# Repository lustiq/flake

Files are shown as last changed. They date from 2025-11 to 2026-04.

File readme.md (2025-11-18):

**English** | [简体中文](./docs/internationalization/Chinese/readme.md) | [Русский](./docs/internationalization/Russian/readme.md) | *`More languages are in progress!`*

***

<div align="center">
    Flake Keyboard Poster
    <h3>Anywhy Flake</h3>
    <p><i>An open-source, wireless, split ergonomic keyboard designed to be productive, healthy, and enjoyable.</i></p>
    <p>
        
        
        
    </p>
</div>

## Why Flake?

By the 19th century, a need for a faster way of writing had emerged, leading to the invention of typewriters. Two centuries later, modern keyboards don't look much different, even though their monolithic, row-staggered design has been proven to be inefficient and often harmful.

The Flake keyboard addresses these problems from the ground up, providing huge benefits in comfort and efficiency for anyone who spends their day typing.

## Core Features

*   **Split Ergonomic Design:** Place each half where it feels best, eliminating wrist strain.
*   **Columnar Stagger:** Keys are arranged to follow the natural movement of your fingers.
*   **Wireless First:** True wireless freedom with Bluetooth LE powered by ZMK Firmware.
*   **Hybrid Hot-Swap:** Supports **MX**, **Kailh Choc v1** and **Kailh Choc v2** switches.
*   **Three Sizes:** Choose the layout that fits you perfectly: **Small (40)**, **Medium (46)**, or **Large (58)** keys.
*   **Ultra-Thin Profile:** An incredibly sleek and low-profile body for maximum comfort.
*   **Fully Open Source:** All hardware and software files are available for you to build, modify, and share.

## The Philosophy Behind the Design

### Split Layout
Regular keyboards force your forearms to converge, bending your wrists at an unnatural angle that can lead to long-term pain. A split keyboard allows you to position each half independently, aligning your hands, wrists, and forearms in a straight, comfortable line. As a bonus, you get free space between the halves for a trackpad, notebook, or even a cat =^..^=

Ergonomic positioning of a split keyboard

### Columnar Stagger
Look at your hand - your fingers have different lengths and prefer to move up and down. Now look at a traditional keyboard - the keys are shifted horizontally. This "row stagger" forces your fingers to make awkward, unnatural movements. Flake uses a "columnar stagger", where each column is shifted vertically to match the natural reach of your fingers, resulting in a much more pleasant and efficient typing experience.

row-based stagger keyboard image

Comparison of row stagger and column stagger

### Hybrid Switch Support
The world of mechanical switches is vast and exciting, but choosing just one type can be limiting. Flake solves this with hybrid hot-swap sockets. Each key position has sockets for both **Cherry MX-style** and **low-profile Kailh Choc** switches. This gives you the freedom to experiment with different switch types at any time.

To provide the best typing feel and stability for the taller MX switches, a dedicated switch plate is included with the case files. This plate is placed over the PCB before inserting the switches, ensuring they are held securely. Low-profile Choc switches mount directly and do not require the plate.

Flake keyboard showing both MX and Choc switches

### Fewer Keys, More Power
A small key count might seem counterintuitive for productivity, but it's a core feature, not a compromise. Fewer keys mean your hands stay in one place, eliminating the need to stretch for distant keys.

This doesn't mean less functionality. Powered by the incredible [ZMK Firmware](https://zmk.dev), Flake uses [layers](https://zmk.dev/docs/keymaps#layers) to access every key a traditional keyboard has and more. You can have dedicated layers for numbers, symbols, navigation, macros, and anything else you can imagine, all just a thumb press away.

Visual representation of keyboard layers in ZMK

To accommodate different preferences, Flake comes in three sizes:
*   **Flake L (58 keys):** For those who prefer more dedicated keys.
*   **Flake M (46 keys):** A perfect balance of function and form.
*   **Flake S (40 keys):** For the ultimate in minimalism and ergonomics.

Flake L keyboard

### Ultra-Thin Profile
The keyboard body is only **~9mm** thick (without feet). Combined with low-profile Choc switches and keycaps, this creates an extremely low-to-the-desk typing experience, further reducing wrist strain.

Side profile showing the thinness of the Flake keyboard

## Build Your Own Flake

Ready to build one? The comprehensive build guide has everything you need to get started.
➡️ **[Read the Official Build Guide](./docs/build_guide.md)**

Also, be sure to check out the gallery to see amazing builds from the community!
➡️ **[Explore the Gallery ✨](./docs/gallery.md)**

## Credits

Huge thanks to:
-   [@foostan](https://github.com/foostan) for the [Corne Keyboard](https://github.com/foostan/crkbd), my introduction to the world of ergonomic keyboards.
-   [@pashutk](https://github.com/pashutk) for the [Chocofi](https://github.com/pashutk/chocofi), an amazing tiny keyboard I've been using for a while.
-   [@josefadamcik](https://github.com/josefadamcik) for the [Sofle](https://github.com/josefadamcik/SofleKeyboard), which heavily inspired the Flake's key layout.
-   [@carrefinho](https://github.com/carrefinho) for the [Forager](https://github.com/carrefinho/forager). Its clever controller mount allowed v2 to use the Seeed Xiao controller while keeping the keyboard thin.
-   [@ebastler](https://github.com/ebastler/) for his amazing [marbastlib](https://github.com/ebastler/marbastlib), which is used as the basis for the switch footprints.
-   [@petejohanson](https://github.com/petejohanson) and all the [contributors](https://github.com/zmkfirmware/zmk/graphs/contributors) for creating and maintaining the incredible [ZMK Firmware](https://github.com/zmkfirmware/zmk).
-   Everyone working on [KiCad](https://gitlab.com/kicad/code/kicad) and [FreeCAD](https://github.com/FreeCAD/FreeCAD) for creating such powerful open source tools.
-   The helpful and kind people from the [ZMK Discord server](https://zmk.dev/community/discord/invite) who helped me learn PCB design and solve countless problems.
-   Thank you to everyone who explores unpopular technologies, digs into niche topics, and makes amazing things possible.

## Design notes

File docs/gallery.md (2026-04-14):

# Anywhy Flake Gallery

Welcome to the gallery, here you will find amazing Flake builds made by people. This page will be constantly expanding, so if you have a build you want to share, feel free to contact me and I'll add it here.

## by [@Constant_Pin_7757](https://www.reddit.com/r/ErgoMechKeyboards/comments/1q6lvwh/comment/ny8om0r/)

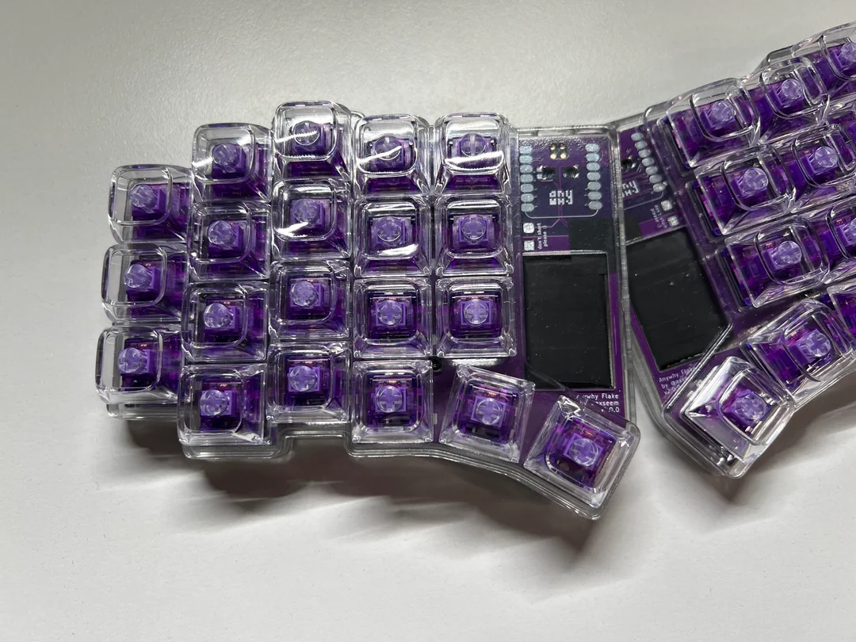
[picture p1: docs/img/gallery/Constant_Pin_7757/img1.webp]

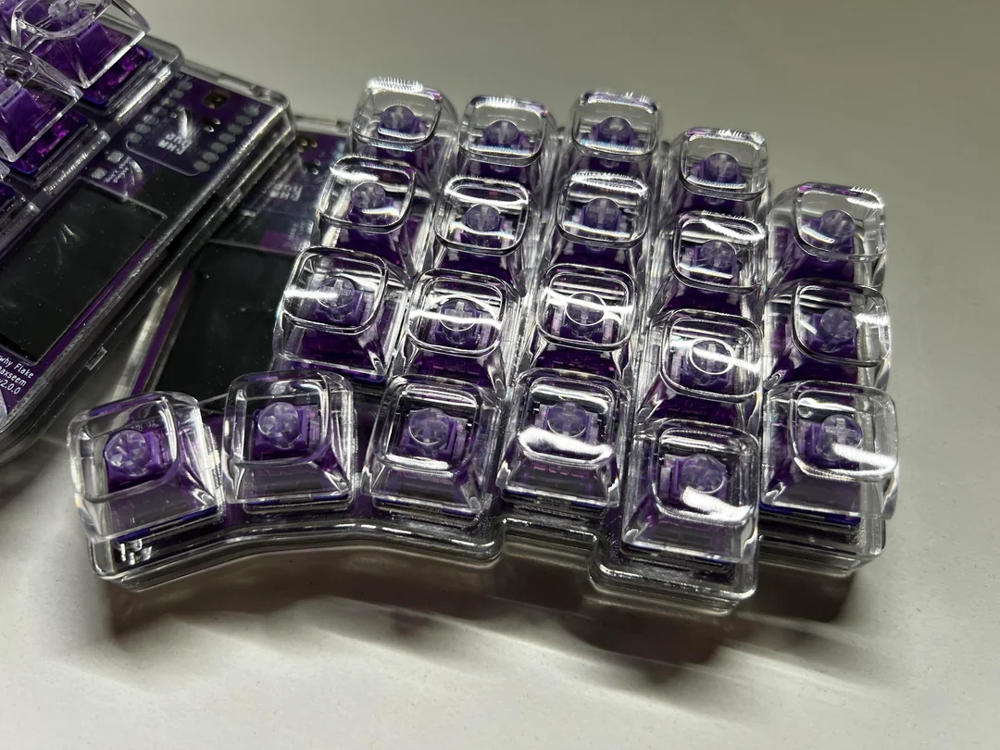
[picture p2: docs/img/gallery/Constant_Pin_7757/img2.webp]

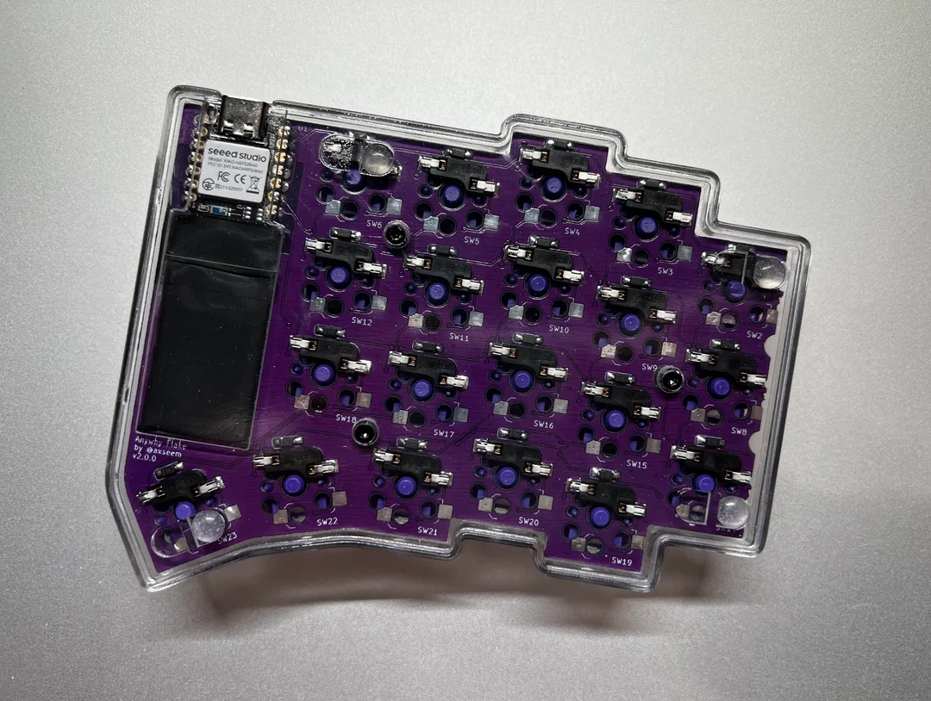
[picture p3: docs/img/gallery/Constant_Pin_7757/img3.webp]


Flake S with transparent housing, lavender PCB and MX switches

## by [@peppapighs](https://www.reddit.com/r/ErgoMechKeyboards/comments/1jbw0kt/my_custom_flake/)

flake image
flake image

Flake S with modified PCB adding through-holes for MCU mounting

## by [@caiodelgado](https://www.reddit.com/r/ErgoMechKeyboards/comments/1iz07kw/anywhy_flake_choc_v1_robinsunset_tenting/)

Flake with Choc v1 Robin switches, 3d-printed keycaps and tenting legs

flake image
flake image

## by [@kurisutofujp](https://www.reddit.com/r/ErgoMechKeyboards/comments/1iirgyt/comment/mb9034h/)

Snow-white Flake L with MX switches

flake image

## by [@devpew](https://www.reddit.com/r/ErgoMechKeyboards/comments/1ieevvh/flake/)

Clean white Flake M with black keyscaps

flake image

## by [@CaptLynx](https://www.reddit.com/r/ErgoMechKeyboards/comments/1ic3nkc/caitlynarcane_themed_anywhy_flake/)

The design is inspired by Caitlin, a character from the Arcane series.

flake image

flake image

flake image

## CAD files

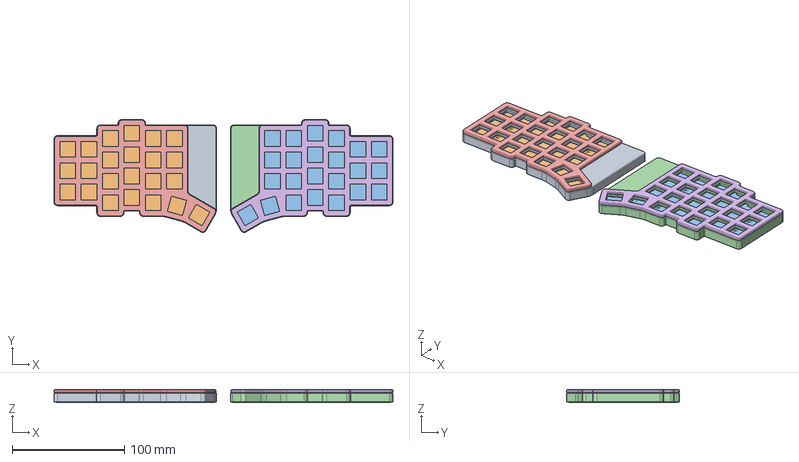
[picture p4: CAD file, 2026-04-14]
enclosure/Enclosure.FCStd
301.4 x 100.4 x 11.3 mm
Top-Left
Bottom-Left001
Bottom-Right001
Top-Right
Plate-Left
Plate-Right

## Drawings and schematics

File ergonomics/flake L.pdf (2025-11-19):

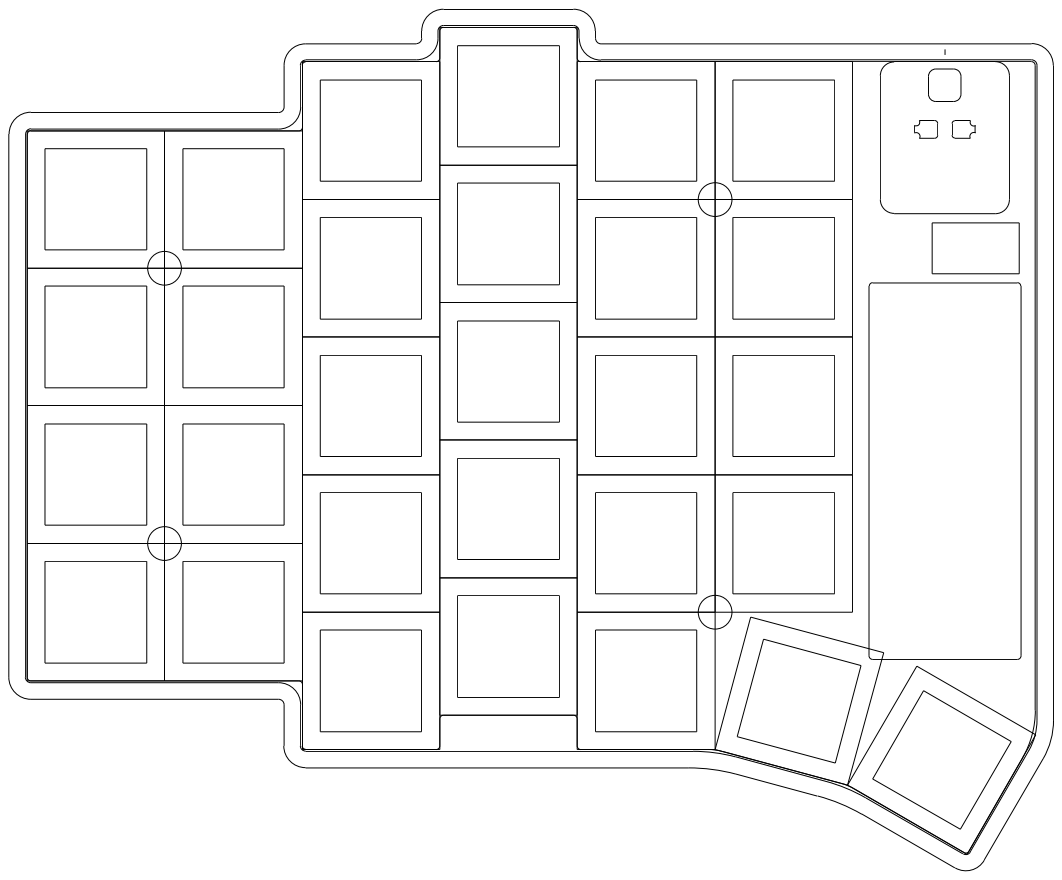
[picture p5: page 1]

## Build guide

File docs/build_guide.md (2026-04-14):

**English** | [简体中文](./internationalization/Chinese/build_guide.md) | [Русский](./internationalization/Russian/build_guide.md)

# Flake Keyboard Build Guide

Welcome to the official build guide for the Flake keyboard! This guide is designed to be comprehensive and easy to follow, even if this is your first time building a keyboard.

I recommend reading through the entire guide once before you begin to familiarize yourself with the process.

## Prerequisites

Before you start soldering or assembling, make sure you have all the necessary components and tools.

### Required Tools

- **Soldering Iron:** A quality soldering iron with adjustable temperature control is essential.
- **Solder:** Lead-free solder is strongly recommended for health and safety.
- **Flux:** A flux pen or paste will make soldering significantly easier.
- **Tweezers:** Essential for handling small components.
- **Screwdriver:** For the M2 screws used in the case.
- **(Optional) Multimeter:** Useful for troubleshooting.

### Required Files

You will need the manufacturing files for the PCB and the enclosure. You can find all the necessary files and instructions on where to order them here:
➡️ **[Essential Files and Ordering Guide](essential_files.md)**

### Bill of Materials (BOM)

The required components vary based on the size of the keyboard you are building. The number of keys for each size is:

- **Small:** 40 keys
- **Medium:** 46 keys
- **Large:** 58 keys

| Component | Small (40) | Medium (46) | Large (58) | Notes |
| :---| :---: | :---: | :---: | :--- |
| **Soldering Components** | | | | |
| Anywhy Flake v2 PCB | 2 | 2 | 2 | One for each half |
| Seeed Xiao nRF52840 | 2 | 2 | 2 | The microcontroller |
| JST 1.25 SMD 2pin Horizontal Connector | 2 | 2 | 2 | For the battery |
| MX Hot-swap Sockets | 40 | 46 | 58 | See note below |
| Choc Hot-swap Sockets | 40 | 46 | 58 | See note below |
| 1N4148 Diodes | 40 | 46 | 58 | 1 per switch (SOD-123 or SOD-323) |
| **Assembly Components** | | | | |
| Soldered PCB | 2 | 2 | 2 | From the step above |
| Switches (Choc v1/v2 or MX) | 40 | 46 | 58 | 1 per socket |
| Keycaps | 40 | 46 | 58 | Must be compatible with your switches |
| Enclosure | 1 set | 1 set | 1 set | Includes top and bottom parts for each half |
| 502030 LiPo Battery (up to 502050 for Flake L) | 2 | 2 | 2 | Or smaller, with a JST 1.25 plug |
| 6x2mm Rubber Feet | 8 | 8 | 8 | |
| M2x4mm Stand-offs | 6 | 8 | 8 | |
| M2x4mm Flat Countersunk Screws | 12 | 16 | 16 | e.g., DIN965 |

> [!NOTE]
> **Sockets:** The Flake PCB supports both MX and Choc switches simultaneously. This guide shows you how to solder both socket types for maximum flexibility. If you are certain you will only ever use one type of switch, you can choose to solder only the corresponding sockets (MX or Choc) and omit the other set.

---

## 1. Soldering the PCB

This is the most detailed part of the build. Take your time, work in a well-ventilated area, and double-check your work as you go. Always use flux, start with a small amount of solder and add more if needed.

### Preparation

#### A. Understand the Reversible PCB

The Flake uses a **reversible PCB**. This means you use the same PCB design for both the left and right halves - you just flip one over. The assembly process is identical for both halves. This guide will walk you through building one half. **Simply repeat all steps on the second PCB, ensuring it is flipped to the opposite side.**

Two reversible Flake PCBs

#### B. Clean the Holes Under the Controller

Due to the manufacturing process, the controller pin holes may be partially obstructed. Before placing the controller, you must carefully clear these obstructions using a tip of your tweezers.

Before and after cleaning the controller pin holes

#### C. Break the PCB (Small Version Only)

If you are building the 40-key **Small** version, as I do in this guide, you must snap off the outer pinky column from both PCBs. **If you are building the Medium or Large version, skip this step and leave the PCBs intact.**

Breaking off the outer column for the Small version

#### D. Prepare Your Components

Lay out the PCB and the components you will be soldering for one half.

All components for soldering one PCB half

### Step 1: Battery Connector (JST)

> [!TIP]
> If your battery doesn't have a JST plug, you can solder it directly to the `RAW` (+) and `GND` (-) pads next to the JST footprint. However, this is not recommended as it makes the battery difficult to replace later.

1. Place the JST 1.25 connector onto its footprint at position `BT1`.
2. Solder the two large mounting pads to secure connector.
3. Solder the two small pins.

Soldering the JST battery connector

### Step 2: Controller (Seeed Xiao)

> [!IMPORTANT]
> Proper alignment is critical. A misaligned controller may prevent the keyboard from fitting into the enclosure.

1. Place the Xiao controller onto its footprint inside the `U1` outline. The USB-C port should face outwards.
2. Solder **one corner pin** to tack the controller in place.
3. Check the alignment. If it's crooked, re-heat the pin and adjust.
4. Once aligned, solder the **diagonally opposite corner pin** to lock it in place.

Tacking opposite corner pins of the controller first

5. Proceed to solder all remaining pins.

All controller pins soldered

6. Flip the PCB and solder the `RAW` and `GND` pads under the controller.

Soldering the RAW and GND pads under the controller

### Step 3: Diodes

> [!WARNING]
> Diodes are directional! The line on the diode must match the line on the PCB silkscreen. An incorrectly oriented diode will cause that key to fail.

For each switch position:

1. Add a small amount of solder to one of the two diode pads.
2. Using tweezers, slide a diode into place, re-heating the solder blob to secure one side. **Ensure the line on the diode aligns with the line on the PCB outline.**
3. Solder the other leg of the diode.

Three-step process for soldering a diode

#### Optional: Check the operational functionality

1. Flash the **left** firmware as per [Flashing Guide](flashing_guide.md) on **both** keyboard Controllers
2. Connect one keyboard half via USB-C to your host
3. Use Via either in [browser](https://www.usevia.app/) or install the [app](https://github.com/cebby2420/via-desktop)
4. Start Via, select your keyboard, go to the keyboard tester and use some solder wire or tweezers to bridge each socket's pad. You should hear a sound and see that the respective key was pressed in the keyboard tester UI. If both halfes work, you can continue with the next steps and should not run into any bigger issues, as you just tested that all Diodes work as well as all connection to the Controller

### Step 4: Hot-swap Sockets

For each switch position:

1. Place the **MX socket** in the top position and the **Choc socket** in the bottom position.
2. Solder both metal legs on each socket.

Soldering MX and Choc hot-swap sockets

### Soldering Complete

Congratulations! You have a fully soldered PCB. Take a moment to inspect all your solder joints.

Completed PCB with all components soldered

Now, repeat the entire soldering process for the second PCB. Remember to work on the **opposite side** of the PCB so it becomes a **mirror image** of the first half.

## 2. Case Assembly

With both PCBs soldered, it's time to put everything into the enclosure.

1. Gather the soldered PCB, case parts, battery, standoffs, and screws.

All components for final assembly

2. Screw the M2x4mm standoffs into the **bottom half** of the case.

Standoffs installed in the bottom plate

3. Seat the soldered PCB into the **top half** of the case. Connect the battery's JST plug and place the battery into its dedicated cutout.

> [!WARNING]
> **Battery Safety:** Triple-check the polarity before connecting battery. Connecting the battery backwards (red wire to `GND (-)`, black wire to `RAW (+)`) will destroy the microcontroller.

PCB and battery placed in the top case

4. Carefully place the bottom plate onto the top part, aligning the standoff holes. Stick the self-adhesive rubber feet onto the dedicated spots on the bottom of the case.

> [!TIP]
> For the second half, place the feet on the opposite corners. This allows the two halves to sit flush against each other back-to-back for transport.

Assembled case from the bottom with rubber feet

5. Insert the M2x4mm screws from the top and tighten them. Do not overtighten.

Screws installed from the top to secure the case

**Repeat** this assembly process for the second half of the keyboard.

## 3. Final Assembly

> [!IMPORTANT]
> If you are using MX switches, you must place the included MX plate onto the keyboard _before_ inserting the switches.

1. **Insert Switches:** Gently press your chosen switches (MX or Choc) into the corresponding hot-swap sockets. Ensure the switch pins are straight to avoid bending them.

Inserting either MX or Choc switches

2. **Install Keycaps:** Press your keycaps firmly onto the switch stems.

Fully assembled Flake keyboard

## You're Done

Congratulations on building your Flake keyboard! Your keyboard is now physically complete.

The final step is to flash the firmware to make it fully functional. Please proceed to the next guide:
➡️ **[Flashing Guide](flashing_guide.md)**

## Troubleshooting

1. Check all your solder joints again. Use flux, maybe a lot of flux. It will help creating nice solder joints.
2. Measure all diodes using a multimeter, maybe one was destroyed by too much heat during the solder process. They should all face the same direction (check the PCB again) and pass the test using the multimeter.
3. If you think one key is non-functional: Use a multimeter, press the faulty key or bridge it using a tweezer or a cable, measure respective Pins on the microcontroller for continuity. Use the kicad schema to know which row/col maps to which pins.
4. If you are in doubt, that you killed your Controller, build the testing firmware, flash it to the Controller and test each pin + ground using e.g. some solder wire. In a text editor you should see pin after pin once you bridge them with ground. For more details check the [documentation](https://zmk.dev/docs/troubleshooting/hardware-issues#identifying-issues)

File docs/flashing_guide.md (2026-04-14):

**English** | [简体中文](./internationalization/Chinese/flashing_guide.md) | [Русский](./internationalization/Russian/flashing_guide.md)

# Flake Keyboard Flashing Guide

## Getting the Firmware

Before your keyboard can function, you'll need to flash it with the appropriate firmware. The firmware is available in the [GitHub repository](https://github.com/anywhy-io/flake-zmk-module).

To download the firmware:
1. Visit the repository's [Actions page](https://github.com/anywhy-io/flake-zmk-module/actions)
2. Select the most recent successful build (indicated by a green checkmark)
3. Download the firmware package

Firmware download page

## Flashing Process

### Left Half
1. Connect the left half of your keyboard to your computer via USB
2. Press the reset button twice quickly to enter bootloader mode
   - The keyboard will appear as a storage device in your file manager
3. Locate the firmware file beginning with "anywhy_flake_left..." (with `.uf2` extension)
4. Copy this file to the keyboard's storage device
   - The device will automatically disconnect once flashing is complete

### Right Half
1. Disconnect the left half and connect the right half
2. Repeat the same process using the file beginning with "anywhy_flake_right..."

The keyboard is now fully functional, further steps are optional and only needed in case you want to modify the keymaps.

## Configuring with ZMK Studio

### Initial Connection
1. Reconnect the left half of the keyboard
2. Navigate to [ZMK Studio](https://zmk.studio) website

ZMK Studio USB connection

3. Click the USB button and select "Anywhy Flake" from the device list

### Unlocking the Keyboard

To unlock the keyboard's configuration:

1. Access the second layer by holding down the leftmost thumb key on the right half
2. Press the lowest key in the extra index finger column on the left half

ZMK Studio unlock process

This will give you access to the ZMK Studio interface where you can customize your keyboard's settings.

ZMK Studio interface

### Setting the Layout
1. In the left sidebar, select your keyboard size from the available options
2. This ensures all configurations match your specific Flake variant

ZMK Studio layout selection

## Final Steps

Your Flake keyboard is now ready to use! You can:
- Continue using it via USB connection
- Disconnect the USB cable and switch to Bluetooth mode
- Customize your keyboard's layout and functions using ZMK Studio

Feel free to experiment with different configurations to find the setup that works best for you.
